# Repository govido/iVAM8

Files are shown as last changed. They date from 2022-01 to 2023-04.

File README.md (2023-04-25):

# iVAM8
Custom mod with Anet A6/A8 parts, IDEX System and Voron Stealthburner Extruder 
IDEXVoronAnetMetal 8 -> iVAM8

main
Front
Bottom

Parts used:
- AM8 frame with blind joints
- Anet A6 printer parts
- BTT GTR mainboard
- 2x SB2040 CANbus boards
- UCAN USB Adapter
- 2x Sony nozzle cams
- 1x Raspi cam
- 24V 360W power supply
- Squashballs as dampening feet
- 2x NEMA14 Voron CW2 extruders
- 2x Voron Stealthburner
- 2x E3D V6
- 1x BLtouch
- TR8x2 Leadscrews
- 12864 mini from Fysetc
- ...
- Lots of M3 and M4 screws and nuts

Features:
- IDEX system with CANbus toolheads
- 3 cameras
- 280mm+ buildheight (shorter with original Z parts)
- Wemos relay in the power box, controlled by Raspberry Pi, controlling the 24V PSU
- Vertical Y-Axis
- Electronics under the printer, making the top ready to be enclosed
- Powered by Klipper
- All parts are designed to print without supports

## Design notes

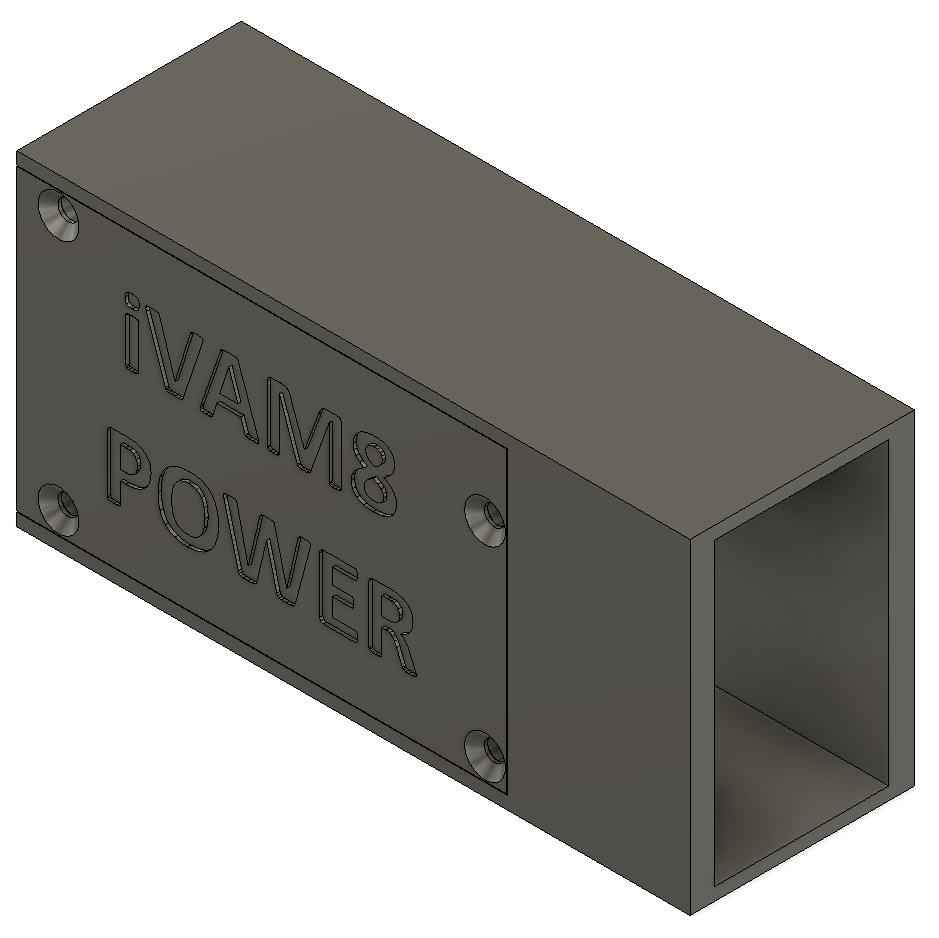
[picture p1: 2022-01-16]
Printed parts STLs/Electronics/iVAM8 powerbox.png

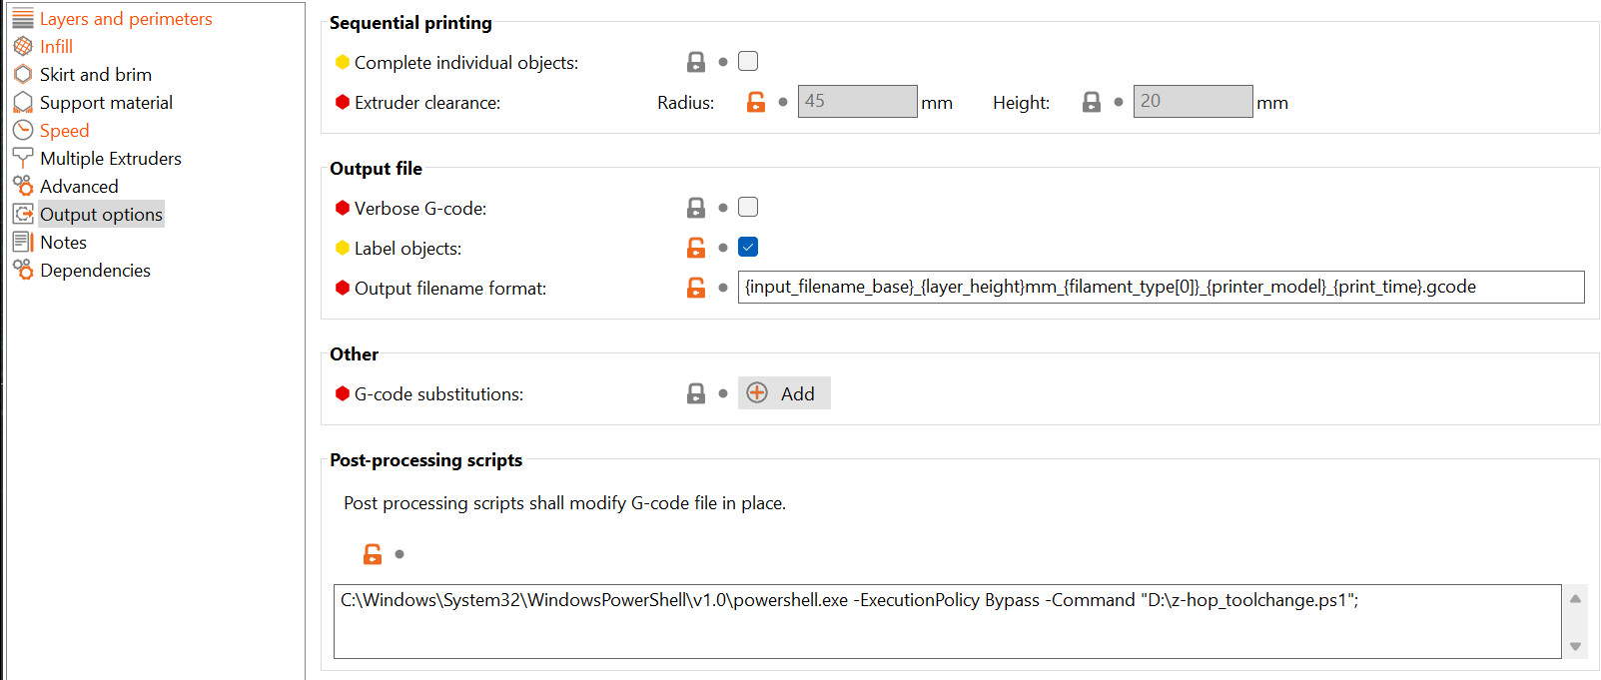
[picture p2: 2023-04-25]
Z-Hop Toolchange Script/Prusaslicer settings.png

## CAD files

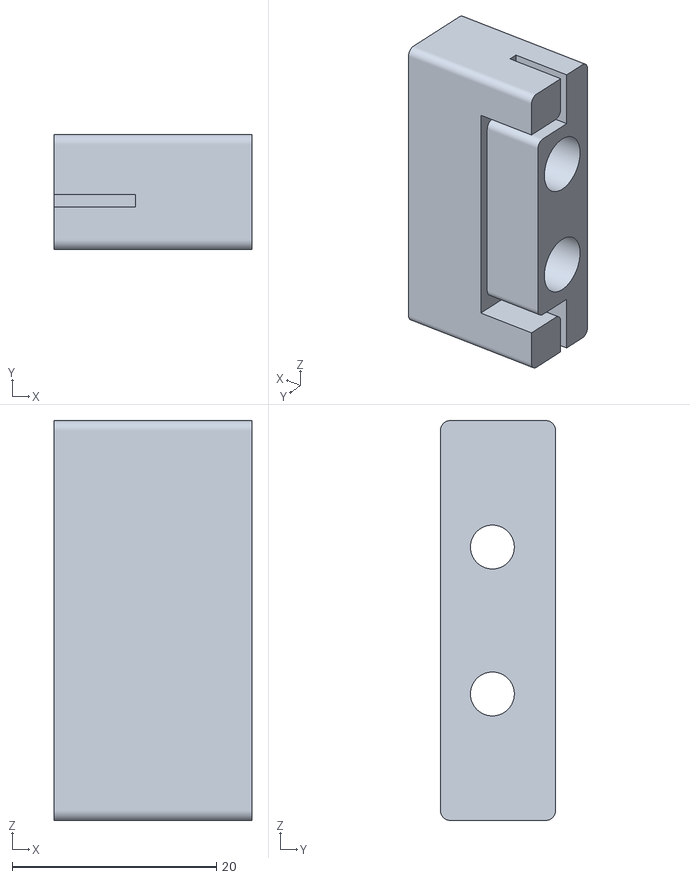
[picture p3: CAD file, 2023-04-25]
Printed parts STLs/Electronics/V2 4x Din_rail_mount.stl
19.4 x 11.3 x 39.2

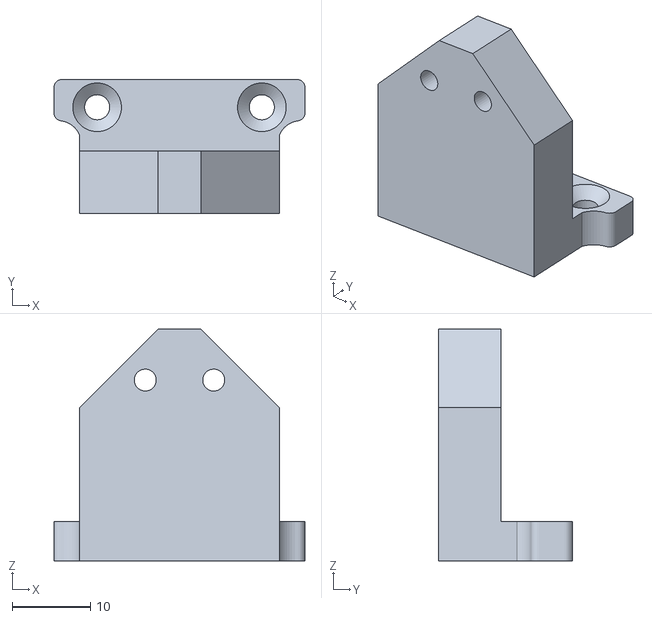
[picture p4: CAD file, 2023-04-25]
Printed parts STLs/X-axis/V2_2x_Oozestop_mount.stl
32.0 x 17.1 x 29.6

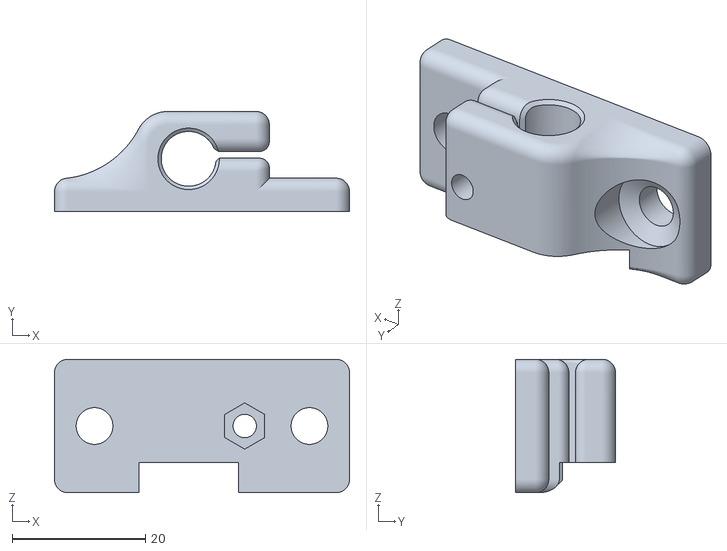
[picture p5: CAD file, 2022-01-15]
Printed parts STLs/Y-axis/y-rod_holder_short.stl
44.2 x 15.0 x 20.0

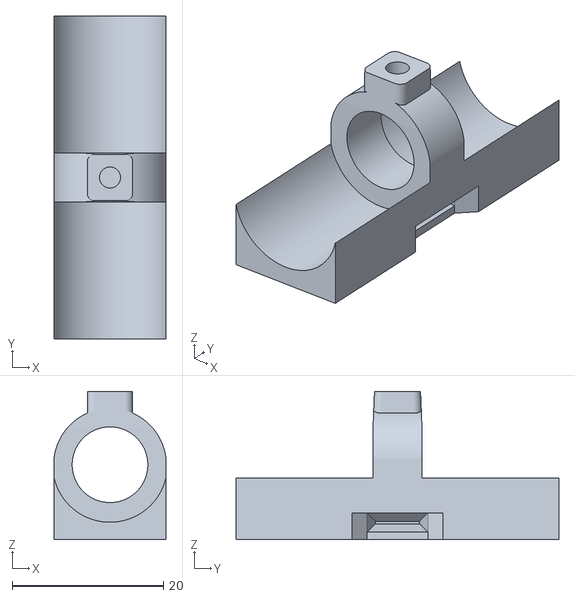
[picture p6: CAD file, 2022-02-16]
Printed parts STLs/Z-axis/V3_2x Z-bearing-mount.stl
14.8 x 42.7 x 19.6

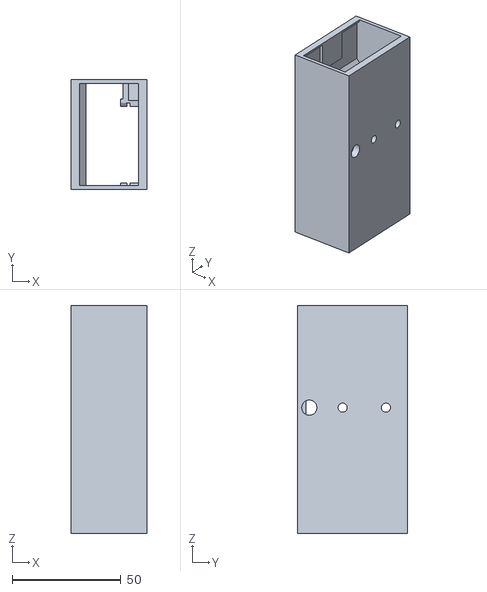
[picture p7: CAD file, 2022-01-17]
Printed parts STLs/Electronics/V5-powerbox.stl
35.0 x 50.8 x 105.0

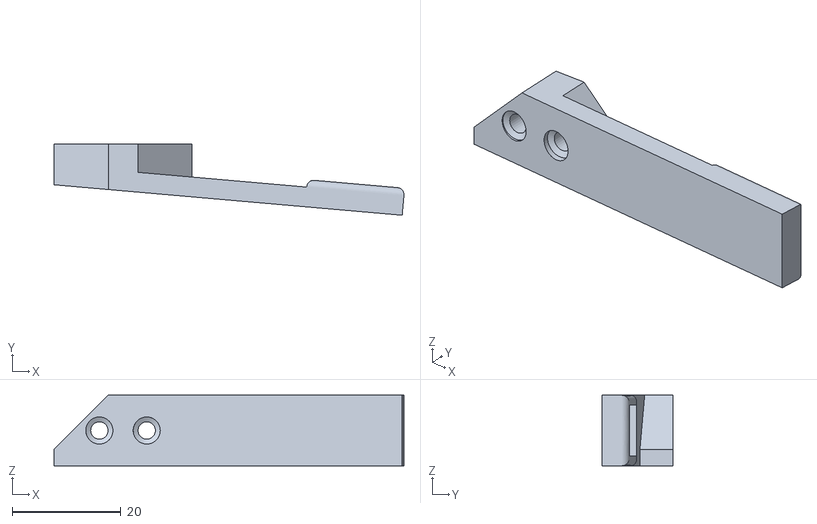
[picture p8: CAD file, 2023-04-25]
Printed parts STLs/X-axis/V2_Oozestop_left.stl
64.5 x 13.2 x 13.0

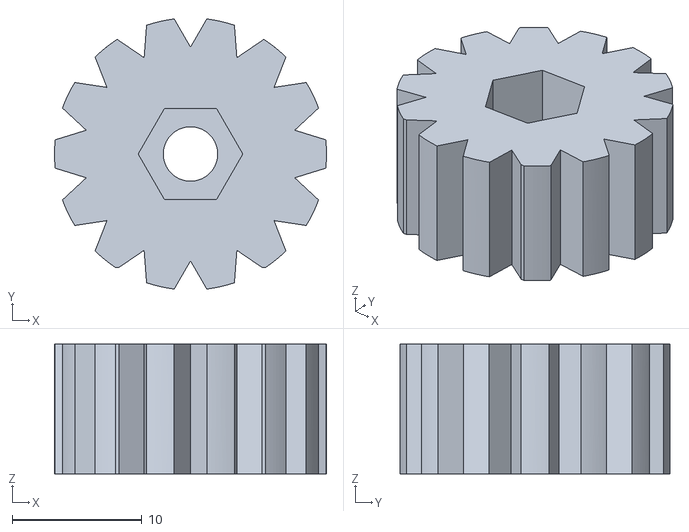
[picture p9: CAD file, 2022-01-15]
Printed parts STLs/Y-axis/y-knob.stl
21.0 x 20.8 x 10.0

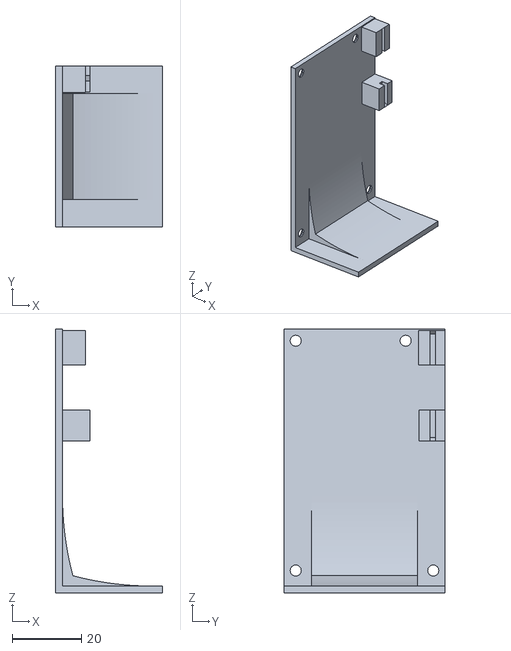
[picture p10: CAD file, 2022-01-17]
Printed parts STLs/Electronics/V5-powerbox_cover.stl
30.9 x 46.6 x 76.4

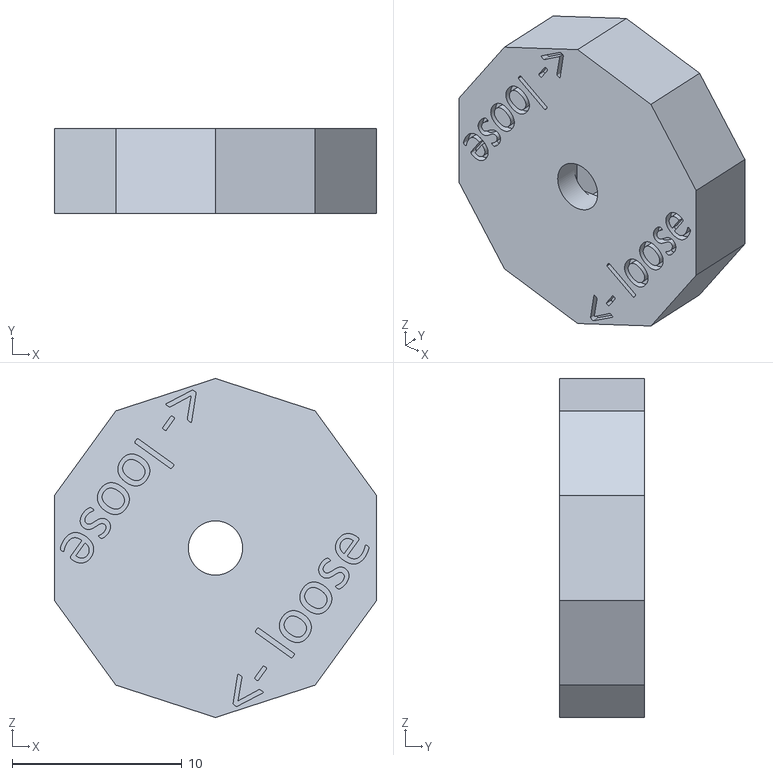
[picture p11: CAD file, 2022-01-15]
Printed parts STLs/Y-axis/bed_knob.stl
19.0 x 5.00 x 20.0

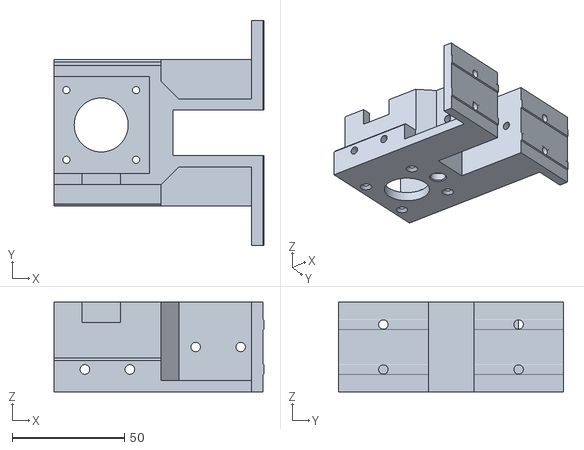
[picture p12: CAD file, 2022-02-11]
Printed parts STLs/Z-axis/v11-Z_motor_left_anti-wobble.stl
93.4 x 100.2 x 40.0

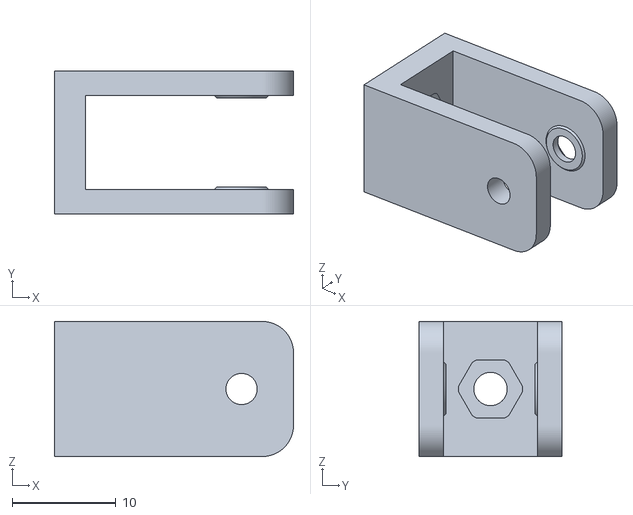
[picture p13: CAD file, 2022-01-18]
Printed parts STLs/X-axis/V9 2x X-Idler.stl
23.0 x 13.8 x 13.0

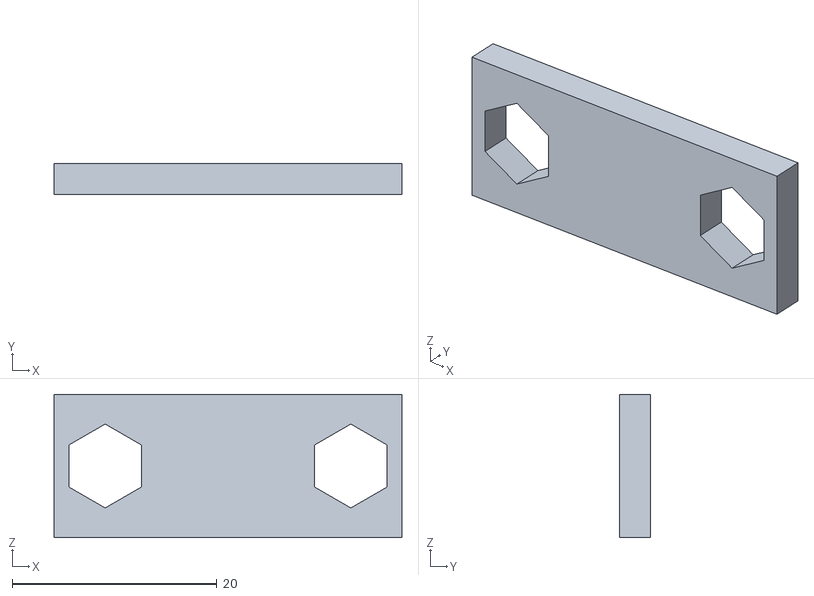
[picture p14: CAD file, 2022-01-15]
Printed parts STLs/Y-axis/4x m4 holder bed.stl
34.0 x 3.00 x 14.0

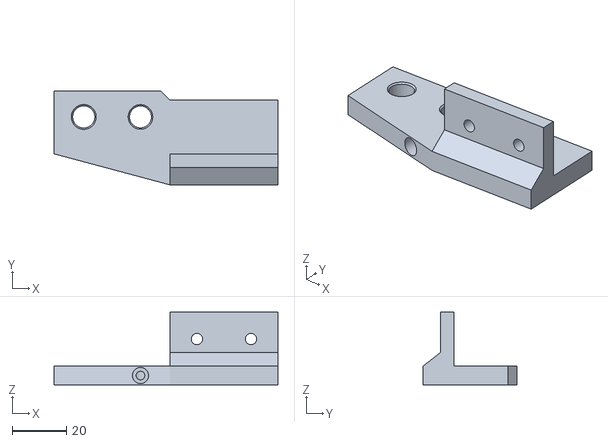
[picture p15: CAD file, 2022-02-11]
Printed parts STLs/Z-axis/V12_Z_top_left_anti-wobble.stl
82.9 x 34.7 x 27.0

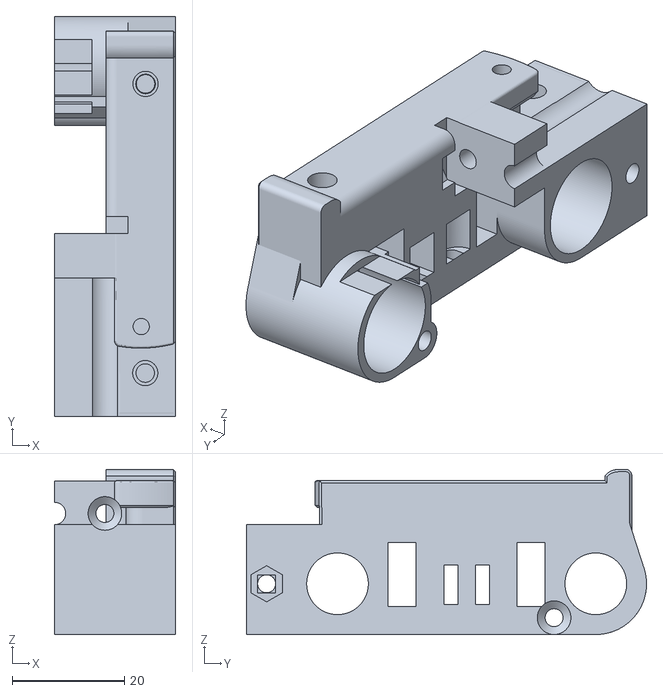
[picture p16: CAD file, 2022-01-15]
Printed parts STLs/X-axis/V12_Carriage_left.stl
21.6 x 71.4 x 29.4

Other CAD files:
Printed parts STLs/X-axis/V2_Oozestop_right.stl
Printed parts STLs/Electronics/V5-powerbox_cover_iVAM8.stl
Printed parts STLs/Electronics/V4-power2_letter_variant.stl
Printed parts STLs/Y-axis/y-tensioner.stl
Printed parts STLs/Electronics/PSU-left.stl
Printed parts STLs/Electronics/PSU-right.stl
Printed parts STLs/Electronics/V2_skr gtr_1.stl
Printed parts STLs/Electronics/V2_skr gtr_2.stl
Printed parts STLs/Electronics/V4-power1.stl
Printed parts STLs/Electronics/V4-power2.stl
Printed parts STLs/Y-axis/Y-Stepper-mount.stl
Printed parts STLs/Y-axis/lm8uu_slim+.stl
Printed parts STLs/Y-axis/y-idler.stl
Printed parts STLs/Z-axis/V12_Z_top_right_anti-wobble.stl
Printed parts STLs/Z-axis/V4_2x_ Z-anti-wobble-nut.stl
Printed parts STLs/Z-axis/v11-Z_motor_right_anti-wobble.stl

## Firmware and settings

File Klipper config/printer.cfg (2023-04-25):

[include shell_command.cfg]
# This file contains common pin mappings for the BigTreeTech GTR.
# To use this config, the firmware should be compiled for the
# STM32F407 with a "32KiB bootloader".

# The "make flash" command does not work on the GTR. Instead,
# after running "make", copy the generated "klipper/out/klipper.bin" file to a
# file named "firmware.bin" on an SD card and then restart the GTR
# with that SD card.

# See docs/Config_Reference.md for a description of parameters.

[include T0-SB2040.cfg]

[include T1-SB2040.cfg]

[include mainsail.cfg]

[include custom_macros.cfg]

[include timelapse.cfg]

#[include lights.cfg]

[include T0-LEDs.cfg]

[include T1-LEDs.cfg]

[include telegram-shaper.conf]

[exclude_object]

[gcode_macro POWER_OFF_PRINTER]
gcode:
  {action_call_remote_method("set_device_power",
                             device="iVAM8",
                             state="off")}

[mcu]
serial: /dev/serial/by-id/usb-Klipper_stm32f407xx_1A003E0015504D5543363820-if00

[printer]
kinematics: cartesian
max_velocity: 300
max_accel: 1500
max_z_velocity: 8
max_z_accel: 7

[firmware_retraction]
retract_length: 0.3
#   The length of filament (in mm) to retract when G10 is activated,
#   and to unretract when G11 is activated (but see
#   unretract_extra_length below). The default is 0 mm.
retract_speed: 60
#   The speed of retraction, in mm/s. The default is 20 mm/s.
unretract_extra_length: 0
#   The length (in mm) of *additional* filament to add when
#   unretracting.
unretract_speed: 60
#   The speed of unretraction, in mm/s. The default is 10 mm/s.

[input_shaper]
shaper_freq_x: 23
shaper_type_x: mzv
shaper_freq_y: 42.2
shaper_type_y: ei

[mcu rpi]
serial: /tmp/klipper_host_mcu

[temperature_sensor pi]
sensor_type: temperature_host
min_temp: 10
max_temp: 100

[adxl345 bed]
cs_pin: rpi:None

[resonance_tester]
probe_points:
   #20,110,2
   110,110,2
   #200,110,2  
   #200,110,50
   110,110,50
   #20,110,50
   #20,110,100
   110,110,100
   #200,110,100 
#  A list of X,Y,Z coordinates of points (one point per line) to test
#   resonances at. At least one point is required. Make sure that all
#   points with some safety margin in XY plane (~a few centimeters)
#   are reachable by the toolhead.
accel_chip_x: adxl345 t0
accel_chip_y: adxl345 bed
#   Names of the accelerometer chips to use for measurements for each
#   of the axis. Can be useful, for instance, on bed slinger printer,
#   if two separate accelerometers are mounted on the bed (for Y axis)
#   and on the toolhead (for X axis). These parameters have the same
#   format as 'accel_chip' parameter. Only 'accel_chip' or these two
#   parameters must be provided.
#accel_chip: adxl345
#   A name of the accelerometer chip to use for measurements. If
#   adxl345 chip was defined without an explicit name, this parameter
#   can simply reference it as "accel_chip: adxl345", otherwise an
#   explicit name must be supplied as well, e.g. "accel_chip: adxl345
#   my_chip_name". Either this, or the next two parameters must be
#   set.
#max_smoothing:
#   Maximum input shaper smoothing to allow for each axis during shaper
#   auto-calibration (with 'SHAPER_CALIBRATE' command). By default no
#   maximum smoothing is specified. Refer to Measuring_Resonances guide
#   for more details on using this feature.
#min_freq: 5
#   Minimum frequency to test for resonances. The default is 5 Hz.
#max_freq: 120
#   Maximum frequency to test for resonances. The default is 120 Hz.
#accel_per_hz: 75
#   This parameter is used to determine which acceleration to use to
#   test a specific frequency: accel = accel_per_hz * freq. Higher the
#   value, the higher is the energy of the oscillations. Can be set to
#   a lower than the default value if the resonances get too strong on
#   the printer. However, lower values make measurements of
#   high-frequency resonances less precise. The default value is 75
#   (mm/sec).
#hz_per_sec: 1
#   Determines the speed of the test. When testing all frequencies in
#   range [min_freq, max_freq], each second the frequency increases by
#   hz_per_sec. Small values make the test slow, and the large values
#   will decrease the precision of the test. The default value is 1.0
#   (Hz/sec == sec^-2).

[force_move]
enable_force_move: True
#   Set to true to enable FORCE_MOVE and SET_KINEMATIC_POSITION
#   extended G-Code commands. The default is false.

# This file contains common pin mappings for the BigTreeTech SKR PRO.
# To use this config, the firmware should be compiled for the
# STM32F407 with a "32KiB bootloader".

# The "make flash" command does not work on the SKR PRO. Instead,
# after running "make", copy the generated "out/klipper.bin" file to a
# file named "firmware.bin" on an SD card and then restart the SKR PRO
# with that SD card.

# See docs/Config_Reference.md for a description of parameters.



[display_status]
[pause_resume]

#Motor 4 as X (M5 Board)
[tmc2209 stepper_x]
uart_pin: PC12
diag_pin: PD3
run_current: 0.600
stealthchop_threshold: 999999
driver_SGTHRS: 120
interpolate: false

[stepper_x]
step_pin: PD1
dir_pin: !PD0
enable_pin: !PD2
microsteps: 128
rotation_distance: 32
#endstop_pin: ^!PI7
position_min: -65.5
position_endstop: -65.5
position_max: 220
homing_speed: 50
endstop_pin: tmc2209_stepper_x:virtual_endstop
homing_retract_dist: 0

[tmc2209 stepper_y]
uart_pin: PE1
diag_pin: PC13
run_current: 0.600
stealthchop_threshold: 999999
driver_SGTHRS: 120
interpolate: false

[stepper_y]
step_pin: PE3
dir_pin: !PE2
enable_pin: !PE4
microsteps: 128
rotation_distance: 32
#endstop_pin: ^!PC13
position_endstop: -40
position_min: -40
position_max: 220
homing_speed: 50
endstop_pin: tmc2209_stepper_y:virtual_endstop
homing_retract_dist: 0

[stepper_z1]
step_pin: PG12
dir_pin: !PG11
enable_pin: !PG13
microsteps: 16
rotation_distance: 2
#endstop_pin: ^!PGI4

[tmc2209 stepper_z1]
uart_pin: PG10
run_current: 0.400
#hold_current: 0.100
stealthchop_threshold: 400
interpolate: false

[stepper_z]
step_pin: PD6
dir_pin: !PD5
enable_pin: !PD7
microsteps: 16
rotation_distance: 2
endstop_pin: probe:z_virtual_endstop
position_min: -2
position_max: 280
homing_speed: 9

[tmc2209 stepper_z]
uart_pin: PD4
run_current: 0.400
#hold_current: 0.100
stealthchop_threshold: 400
interpolate: false

[z_tilt]
z_positions:
  -50,110
  270,110
points:
  30,110
  190,110
speed: 160
retries: 9
retry_tolerance: 0.01

[verify_heater extruder]
#max_error: 240
#   The maximum "cumulative temperature error" before raising an
#   error. Smaller values result in stricter checking and larger
#   values allow for more time before an error is reported.
#   Specifically, the temperature is inspected once a second and if it
#   is close to the target temperature then an internal "error
#   counter" is reset; otherwise, if the temperature is below the
#   target range then the counter is increased by the amount the
#   reported temperature differs from that range. Should the counter
#   exceed this "max_error" then an error is raised. The default is
#   120.
#check_gain_time: 40
#   This controls heater verification during initial heating. Smaller
#   values result in stricter checking and larger values allow for
#   more time before an error is reported. Specifically, during
#   initial heating, as long as the heater increases in temperature
#   within this time frame (specified in seconds) then the internal
#   "error counter" is reset. The default is 20 seconds for extruders
#   and 60 seconds for heater_bed.
#hysteresis: 5
#   The maximum temperature difference (in Celsius) to a target
#   temperature that is considered in range of the target. This
#   controls the max_error range check. It is rare to customize this
#   value. The default is 5.
#heating_gain: 2
#   The minimum temperature (in Celsius) that the heater must increase
#   by during the check_gain_time check. It is rare to customize this
#   value. The default is 2.

[verify_heater extruder1]
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

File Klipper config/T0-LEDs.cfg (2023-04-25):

[neopixel mks_display]
pin: EXP1_6
chain_count: 3
color_order: RGB
initial_RED: 0.5
initial_GREEN: 0.7
initial_BLUE: 0.5
# Macros for setting the status leds on the Voron StealthBurner toolhead (or for any neopixel-type leds).
#
# Use this file if you have a rainbow barf PCB in the logo and two nozzle LEDs.
# Thank you to Urufu_Shinjiro for providing this file.
#
# You will need to configure a neopixel (or other addressable led, such as dotstar). See
# https://www.klipper3d.org/Config_Reference.html#neopixel for configuration details.



#####################################
#           INSTRUCTIONS            #
#####################################
# How to use all this stuff:
#
#     1.  Copy this .cfg file into your Klipper config directory and then add [include stealthburner_leds.cfg]
#         to the top of your printer.cfg in order for register the LEDs and macros with Klipper.
#     2.  Define your LEDs by editing [neopixel t0_sb_leds] below and entering the data pin from your control board
#         as well as the color order.
#
#           Note: RGB and RGBW are different and must be defined explicitly in the color order. 
#
#                 RGBW LEDs will have a visible yellow-ish phosphor section to the chip.  If your LEDs do not have
#                 this yellow portion, you have RGB LEDs.
#
#     3.  Save your config and restart Klipper.
#
#           Note: We set RED and BLUE to 1.0 to make it easier for users and supporters to detect 
#                 misconfigurations or miswiring. The default color format is for Neopixels with a dedicated 
#                 white LED. On startup, all three SB LEDs should light up.
#
#                 If you get random colors across your LEDs, change the color_order to GRB and restart. Then
#                 omit the W for each suggested color_order in the next paragraph.
#
#                 If you get MAGENTA, your  color order is correct. If you get CYAN, you need to use RGBW. If
#                 you get YELLOW, you need to use BRGW (note that BRG is only supported in the latest Klipper
#                 version).
#
#     4.  Once you have confirmed that the LEDs are set up correctly, you must now decide where you want 
#         these macros called up...which means adding them to your existing gcode macros.  NOTHING will happen
#         unless you add the STATUS_????? macros to your existing gcode macros.  
#
#           Example: add STATUS_LEVELING to the beginning of your QGL gcode macro, and then add STATUS_READY 
#                    to the end of it to set the logo LED and nozzle LEDs back to the `ready` state.
#
#           Example: add STATUS_CLEANING to the beginning of your nozzle-cleaning macro, and then STATUS_READY
#                    to the end of it to return the LEDs back to `ready` state.
#
#     5.  Feel free to change colors of each macro, create new ones if you have a need to.  The macros provided below
#         are just an example of what is possible.  If you want to try some more complex animations, you will most
#         likely have to use WLED with Moonraker and a small micro-controller (please see the LED thread for help inside
#         of the stealthburner_beta channel on Discord).
#
#####################################
#       END INSTRUCTRUCTIONS        #
#####################################


[neopixel t0_sb_leds]
pin: T0-SB2040:RGBLED
#   The pin connected to the neopixel. This parameter must be provided.
chain_count: 10
#   The number of Neopixel chips that are "daisy chained" to the
#   provided pin. The default is 1 (which indicates only a single
#   Neopixel is connected to the pin).
color_order: GRB, GRB, GRB, GRB, GRB, GRB, GRB, GRB, GRBW,  GRBW
#   Set the pixel order required by the LED hardware. Options are GRB,
#   RGB, GRBW, or RGBW. The default is GRB.
initial_RED: 1.0
initial_GREEN: 0.0
initial_BLUE: 1.0
initial_WHITE: 0.0
#   Sets the initial LED color of the Neopixel. Each value should be
#   between 0.0 and 1.0. The WHITE option is only available on RGBW
#   LEDs. The default for each color is 0.#



##########################
# LED Effects Animations #
##########################

##################
## logo effects ##
##################

[led_effect t0_sb_logo_busy]
autostart:              false
frame_rate:             24
leds:
    neopixel:t0_sb_leds (1-8)
layers:
    breathing  3 1 top (1,0,0)

[led_effect t0_sb_logo_cleaning]
autostart:              false
frame_rate:             24
leds:
    neopixel:t0_sb_leds (1-8)
layers:
    breathing  3 1 top (0.0, 0.02, 0.5)

[led_effect t0_sb_logo_calibrating_z]
autostart:              false
frame_rate:             24
leds:
    neopixel:t0_sb_leds (1-8)
layers:
        breathing  3 1 top (0.0, 0.0, 0.35)

[led_effect t0_sb_logo_heating]
leds:
    neopixel:t0_sb_leds (1,3,7,8,6,2)
autostart:                          false
frame_rate:                         24
layers:
    comet  0.3  0 add (1, 0.18, 0)

[led_effect t0_sb_logo_heating_nozzle]
leds:
    neopixel:t0_sb_leds (1,2,3,4)
autostart:                          false
frame_rate:                         24
heater: extruder
layers:
    heater 25.00 0.00 top (0.2,0.2,0.00),(.20,0.10,0.00),(0.40,0.00,0.00)


[led_effect t0_sb_logo_heating_bed]
leds:
    neopixel:t0_sb_leds (5,6,7,8)
autostart:                          false
frame_rate:                         24
heater: heater_bed
layers:
    heater 25.00 0.00 top (0.2,0.2,0.00),(.20,0.10,0.00),(0.40,0.00,0.00)


[led_effect t0_sb_logo_cooling]
leds:
    neopixel:t0_sb_leds (1,3,7,8,6,2)
autostart:                          false
frame_rate:                         24
layers:
    comet  0.3  0 add (0, 0, 1)

[led_effect t0_sb_logo_homing]
autostart:              false
frame_rate:             24
leds:
    neopixel:t0_sb_leds (1-8)
endstops: x,y,z,probe
layers:
 homing 15.00 0.00 add (0.69,0.69,0.69) 
 gradient 0.30 0.10 top (0.66,0.00,0.33),(0.00,0.00,0.67),(0.33,0.00,0.67) 

[led_effect t0_sb_logo_leveling_1]
autostart:              false
frame_rate:             24
leds:
    neopixel:t0_sb_leds (1,4,7)
layers:
        chase 0.30 3.00 top (0.56,0.04,0.44),(0.00,0.00,0.70) 

[led_effect t0_sb_logo_leveling_2]
autostart:              false
frame_rate:             24
leds:
    neopixel:t0_sb_leds (2,5,8)
layers:
        comet -0.30 3.00 top (0.56,0.04,0.44),(0.00,0.00,0.70) 

[led_effect t0_sb_logo_leveling_3]
autostart:              false
frame_rate:             24
leds:
    neopixel:t0_sb_leds (3,6)
endstops: x,y,z,probe
layers:
      homing 15.00 0.00 add (0.69,0.69,0.69)



[led_effect t0_sb_logo_meshing]
autostart:              false
frame_rate:             24
leds:
    neopixel:t0_sb_leds (1-8)
layers:
        breathing  3 1 top (0.2, 1.0, 0.0)

[led_effect t0_sb_logo_printing]
autostart:              false
frame_rate:             24
leds:
    neopixel:t0_sb_leds (1-8)
layers:
 progress -1.00 0.00 add (0,0.5,0),(0,0.2,0) 
 twinkle -0.10 0.20 add (0.10,0.10,0.10) 
 breathing 10.00 0.00 add (0.0,0.10,0.0)



    #gradient  0.3  1 add (0.3, 0.0, 0.0),(0.3, 0.3, 0.0),(0.3, 0.1, 0.0)

[led_effect t0_sb_logo_standby]
autostart:              false
frame_rate:             24
leds:
    neopixel:t0_sb_leds (1-8)
layers:
        breathing  3 1 top (0.01, 0.01, 0.01)

[led_effect t0_sb_logo_part_ready]
autostart:              false
frame_rate:             24
leds:
    neopixel:t0_sb_leds (1-8)
layers:
 comet 0.30 6.50 add (0,0.6,0),(0,0.1,0) 

####################
## nozzle effects ##
####################

[led_effect t0_sb_nozzle_heating]
autostart:              false
frame_rate:             24
leds:
    neopixel:t0_sb_leds (9,10)
layers:
        breathing  3 1 top (1.0, 0.18, 0.0, 0.0)

[led_effect t0_sb_nozzle_cooling]
autostart:              false
frame_rate:             24
leds:
    neopixel:t0_sb_leds (9,10)
layers:
        breathing  3 1 top (0.0, 0.0, 1.0, 0.1)

[led_effect t0_sb_nozzle_standby]
autostart:              false
frame_rate:             24
leds:
    neopixel:t0_sb_leds (9,10)
layers:
        breathing  3 1 top (0.6, 0.0, 0.0, 0.0)

[led_effect t0_sb_nozzle_part_ready]
autostart:              false
frame_rate:             24
leds:
    neopixel:t0_sb_leds (9,10)
layers:
       gradient 0.20 1.00 top (0.1,0.0,0.0),(0.0,0.1,0.0),(0.0,0.0,0.1) 



#####################
## all led effects ##
#####################

[led_effect t0_sb_critical_error]
leds:
    neopixel:t0_sb_leds
layers:
    strobe         1  1.5   add        (1.0,  1.0, 1.0)
    breathing      2  0     difference (0.95, 0.0, 0.0)
    static         1  0     top        (1.0,  0.0, 0.0)
autostart:                             false
frame_rate:                            24
run_on_error:                          true


[led_effect t0_rainbow]
leds:
    neopixel:t0_sb_leds
autostart:                          true
frame_rate:                         24
layers:
    gradient  0.3  1 add (0.3, 0.0, 0.0),(0.0, 0.3, 0.0),(0.0, 0.0, 0.3)


#######################
# LED Effects Statics #
#######################
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

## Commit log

2022-01-15 Initial upload of testing alpha parts
    [4x m4 holder bed.stl, PSU-left.stl, PSU-right.stl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]
2022-01-16 new powerbox test
    [V2-power1.stl, V2-power2.stl, V2-power_cover.stl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]
2022-01-16 make powebox text nicer
    [V4-power2_letter_variant.stl]
2022-01-17 initial (unfinished) configs
    [printer.cfg]
2022-01-17 powerbox update
    [V5-powerbox.stl, V5-powerbox_cover.stl, V5-powerbox_cover_iVAM8.stl]
2022-01-18 X-idler update
    [V8 2x X-Idler.stl, V9 2x X-Idler.stl]
2022-01-24 push missing Z STLs
    [V9_Z_top_left.stl, V9_Z_top_right.stl, v9-Z_motor_right.stl]
2022-01-24 Z for bigger idler
    [V10-2x Z.stl]
2022-01-24 Create V11-2x Z_418mm_rod.stl
2022-02-03 Macros test, led effects
    [custom_macros.cfg, lights.cfg, printer.cfg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]
2022-02-08 anti wobble Z concept
    [V3_2x_ Z-anti-wobble-nut.stl, custom_macros.cfg]
2022-02-11 Z redesign
    Complete redesign for motor mounts and various holes for heatset inserts for future add-ons (cable clamps, servos, probes...).
    Motor mounts replace screws for Z-extrusion to move it further back and prohibit tilting back and forward when working on the machine.
    [V11_Z_top_left_anti-wobble.stl, V11_Z_top_right_anti-wobble.stl, V9_Z_top_left.stl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]
2022-02-11 z top fix
    [V11_Z_top_left_anti-wobble.stl, V11_Z_top_right_anti-wobble.stl, V12_Z_top_left_anti-wobble.stl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]
2022-02-11 add missing chamfers and small fixes
    [V12_Z_top_left_anti-wobble.stl, V12_Z_top_right_anti-wobble.stl, V3_2x_ Z-anti-wobble-nut.stl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]
2022-02-12 tiny adjustments
    [V3_2x_ Z-anti-wobble-nut.stl, V4_2x_ Z-anti-wobble-nut.stl]
2022-02-16 renew Z-axis
    [V3_2x Z-bearing-mount.stl]
2023-04-25 Oozestop, new configs, CANbus
    [T0-LEDs.cfg, T0-SB2040.cfg, T1-LEDs.cfg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]
